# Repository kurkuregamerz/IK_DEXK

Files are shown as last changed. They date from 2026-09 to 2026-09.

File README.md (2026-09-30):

# IK DEXK 
IK DEXK is a macropad that has 16 MX Keyboard switches and 1 OLED 0.91 inch Display.

## Preview of Designs  
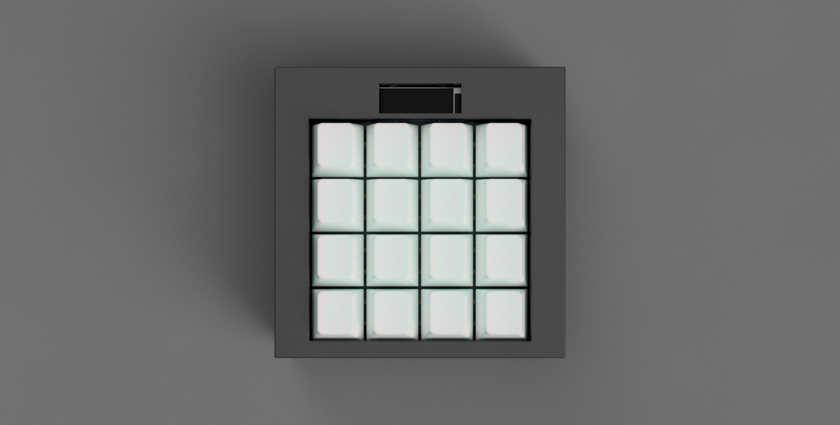
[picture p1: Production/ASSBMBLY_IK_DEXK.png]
  
  
  
  
  
  
## Features
*  It includes an 0.91 inch OLED display.
*  Custom Macros for efficiency.
*  Has high performance Cherry MX Switches with white keycaps.
*  Custom PCB and Case.

## THE PROCESS 
I at first designed the Macropad to be 3x3 but during designing I made some mistakes which later in firmware development caused a huge problem.
So when I ran into that problem I thought that now I know how things work so why not make it larger. That is why I made the macropad 4x4.
Here are some images of design which were used at first.
  
  

# BILL OF MATARIALS
* TOTAL IS $54.86 with delivery charge.<br/>
<table>
  <tr>
    <th>ITEM</th>
    <th>SOURCE</th>
    <th>PRICE</th>
    <th>DELIVERY CHARGE</th>
    <th>TOTAL</th>
  </tr>
  <tr>
    <td>PCB</td>
    <td>JLCPCB</td>
    <td>$ 4.00</td>
    <td>$ -</td>
    <td>$ 4.00</td>
  </tr>
  <tr>
    <td>CASE-BOTTOM</td>
    <td>JLC3DP</td>
    <td>$ 22.34</td>
    <td>$ 24.58</td>
    <td>$ 46.92</td>
  </tr>
   <tr>
    <td>CASE-TOP</td>
    <td>JLC3DP</td>
    <td>$ 3.94</td>
    <td>$ -</td>
    <td>$ 3.94</td>
  </tr>
  <tr>
    <td>HACKPAD KIT</td>
    <td>HACKCLUB</td>
    <td>$ -</td>
    <td>$ -</td>
    <td>$ 0.00</td>
  </tr>
  <tr>
    <td>TOTAL</td>
    <td></td>
    <td>$ 30.28</td>
    <td>$ 24.58</td>
    <td>$ 54.86</td>
  </tr>
</table>

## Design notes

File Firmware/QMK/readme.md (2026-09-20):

# ik_dexk

ik_dexk

*A short description of the keyboard/project*

* Keyboard Maintainer: [Ishan Karar](https://github.com/kurkuregamerz)
* Hardware Supported: *The PCBs, controllers supported*
* Hardware Availability: *Links to where you can find this hardware*

Make example for this keyboard (after setting up your build environment):

    make ik_dexk:default

Flashing example for this keyboard:

    make ik_dexk:default:flash

See the [build environment setup](https://docs.qmk.fm/#/getting_started_build_tools) and the [make instructions](https://docs.qmk.fm/#/getting_started_make_guide) for more information. Brand new to QMK? Start with our [Complete Newbs Guide](https://docs.qmk.fm/#/newbs).

## Bootloader

Enter the bootloader in 3 ways:

* **Bootmagic reset**: Hold down the key at (0,0) in the matrix (usually the top left key or Escape) and plug in the keyboard
* **Physical reset button**: Briefly press the button on the back of the PCB - some may have pads you must short instead
* **Keycode in layout**: Press the key mapped to `QK_BOOT` if it is available

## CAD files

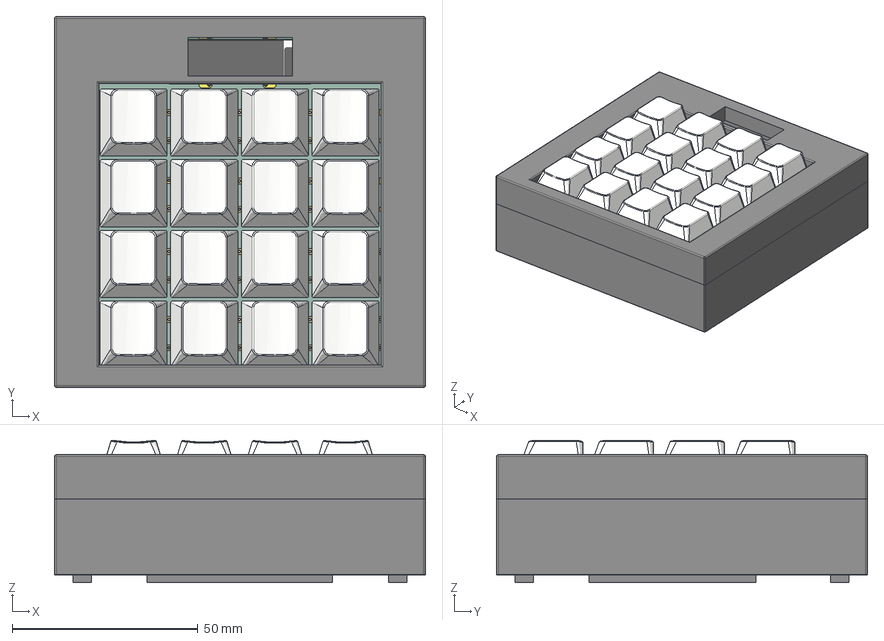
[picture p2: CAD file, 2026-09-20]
CAD/ASSBMBLY_IK_DEXK.step
100.0 x 100.0 x 38.3 mm

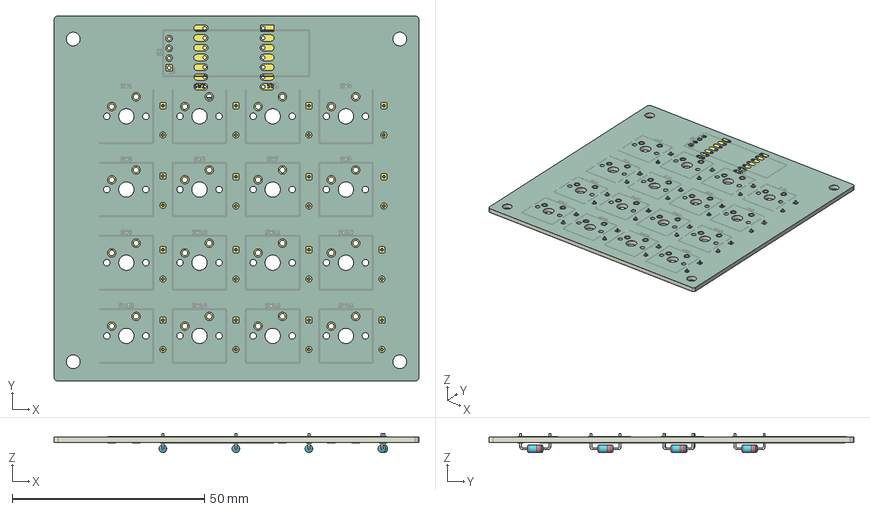
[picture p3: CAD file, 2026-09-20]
pcb/IK_DEXK_PCB.step
95.0 x 95.0 x 5.01 mm
D_DO-35_SOD27_P7.62mm_Horizontal x 16
IK_DEXK_copper
IK_DEXK_silkscreen x 2
IK_DEXK_soldermask x 2
IK_DEXK_PCB

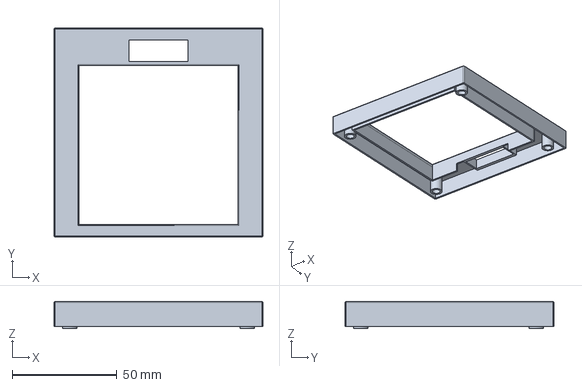
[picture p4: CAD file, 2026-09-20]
Production/CASE TOP.step
100.0 x 100.0 x 13.0 mm

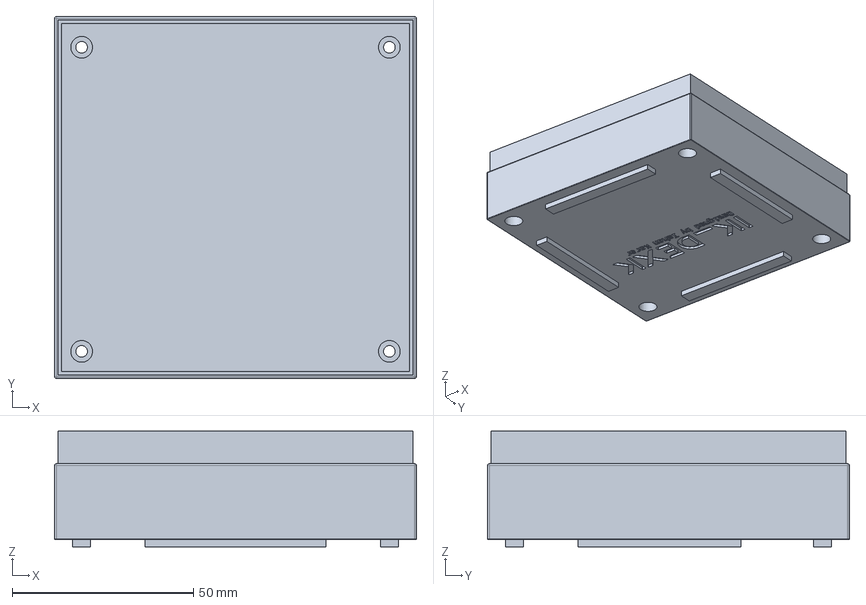
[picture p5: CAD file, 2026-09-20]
Production/CASE BOTTOM.step
100.0 x 100.0 x 32.0 mm

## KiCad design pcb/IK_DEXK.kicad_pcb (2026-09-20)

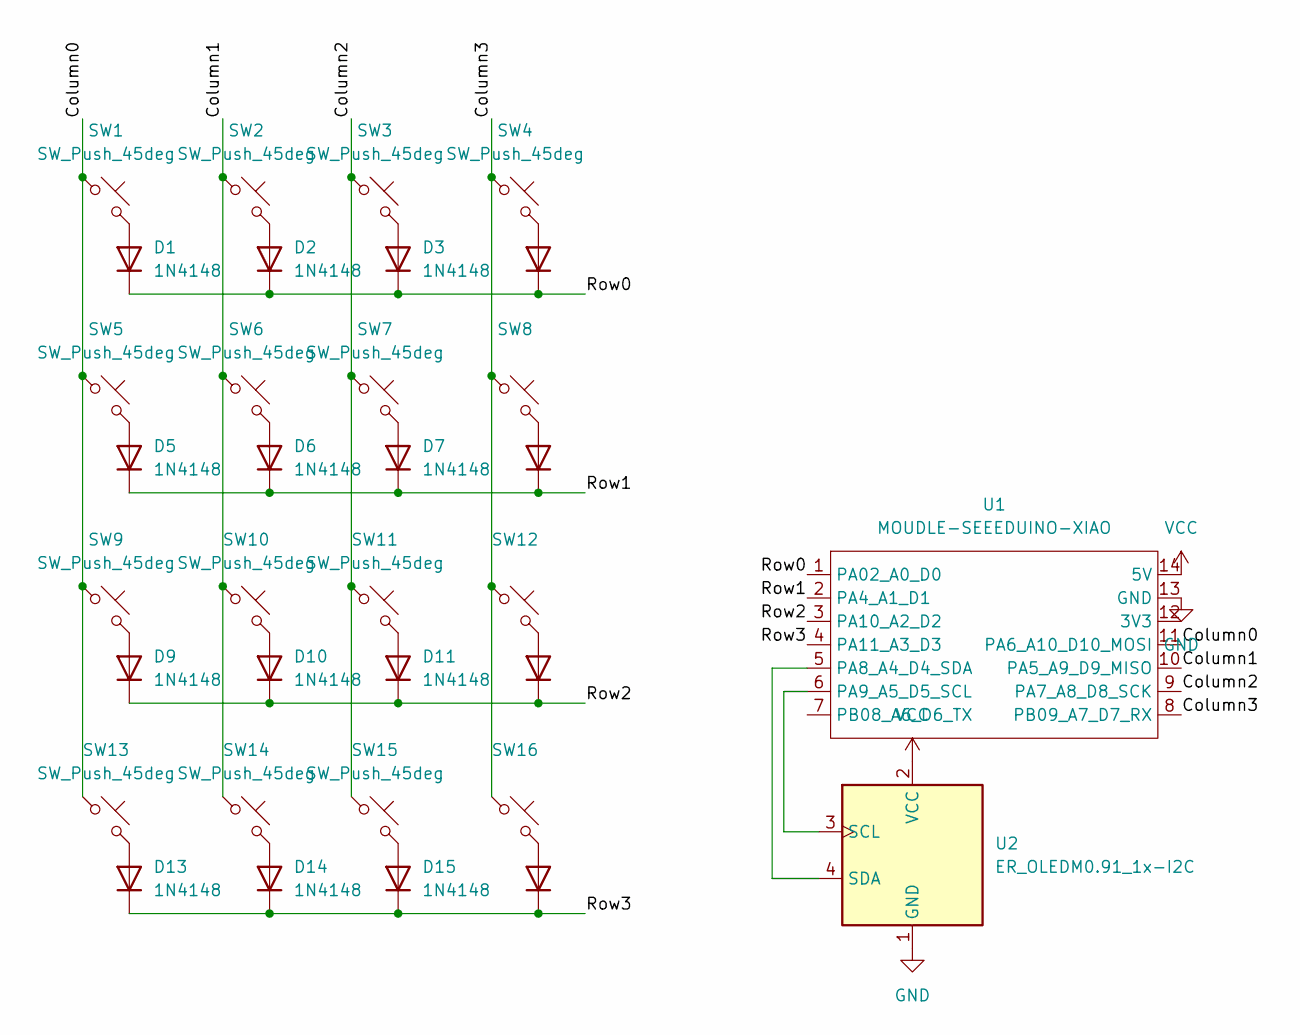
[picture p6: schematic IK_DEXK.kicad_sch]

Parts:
D1, D2, D3, D4, D5, D6, D7, D8, D9, D10, D11, D12, D13, D14, D15, D16: 1N4148; D_DO-35_SOD27_P7.62mm_Horizontal
SW1, SW2, SW3, SW4, SW5, SW6, SW7, SW8, SW9, SW10, SW11, SW12, SW13, SW14, SW15, SW16: SW_Push_45deg; SW_Cherry_MX_1.00u_PCB
U1: MOUDLE-SEEEDUINO-XIAO; XIAO-Generic-Hybrid-14P-2.54-21X17.8MM
U2: ER_OLEDM0.91_1x-I2C

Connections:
/Column0: SW1.1, SW5.1, SW9.1, SW13.1, U1.11 (PA6_A10_D10_MOSI)
/Column1: SW2.1, SW6.1, SW10.1, SW14.1, U1.10 (PA5_A9_D9_MISO)
/Column2: SW3.1, SW7.1, SW11.1, SW15.1, U1.9 (PA7_A8_D8_SCK)
/Column3: SW4.1, SW8.1, SW12.1, SW16.1, U1.8 (PB09_A7_D7_RX)
/Row0: D1.1 (K), D2.1 (K), D3.1 (K), D4.1 (K), U1.1 (PA02_A0_D0)
/Row1: D5.1 (K), D6.1 (K), D7.1 (K), D8.1 (K), U1.2 (PA4_A1_D1)
/Row2: D9.1 (K), D10.1 (K), D11.1 (K), D12.1 (K), U1.3 (PA10_A2_D2)
/Row3: D13.1 (K), D14.1 (K), D15.1 (K), D16.1 (K), U1.4 (PA11_A3_D3)
GND: U1.13 (GND), U2.1 (GND)
unnamed: D1.2 (A), SW1.2
unnamed: D2.2 (A), SW2.2
unnamed: D3.2 (A), SW3.2
unnamed: D4.2 (A), SW4.2
unnamed: D5.2 (A), SW5.2
unnamed: D6.2 (A), SW6.2
unnamed: D7.2 (A), SW7.2
unnamed: D8.2 (A), SW8.2
unnamed: D9.2 (A), SW9.2
unnamed: D10.2 (A), SW10.2
unnamed: D11.2 (A), SW11.2
unnamed: D12.2 (A), SW12.2
unnamed: D13.2 (A), SW13.2
unnamed: D14.2 (A), SW14.2
unnamed: D15.2 (A), SW15.2
unnamed: D16.2 (A), SW16.2
unnamed: U1.5 (PA8_A4_D4_SDA), U2.4 (SDA)
unnamed: U1.6 (PA9_A5_D5_SCL), U2.3 (SCL)
VCC: U1.14 (5V), U2.2 (VCC)

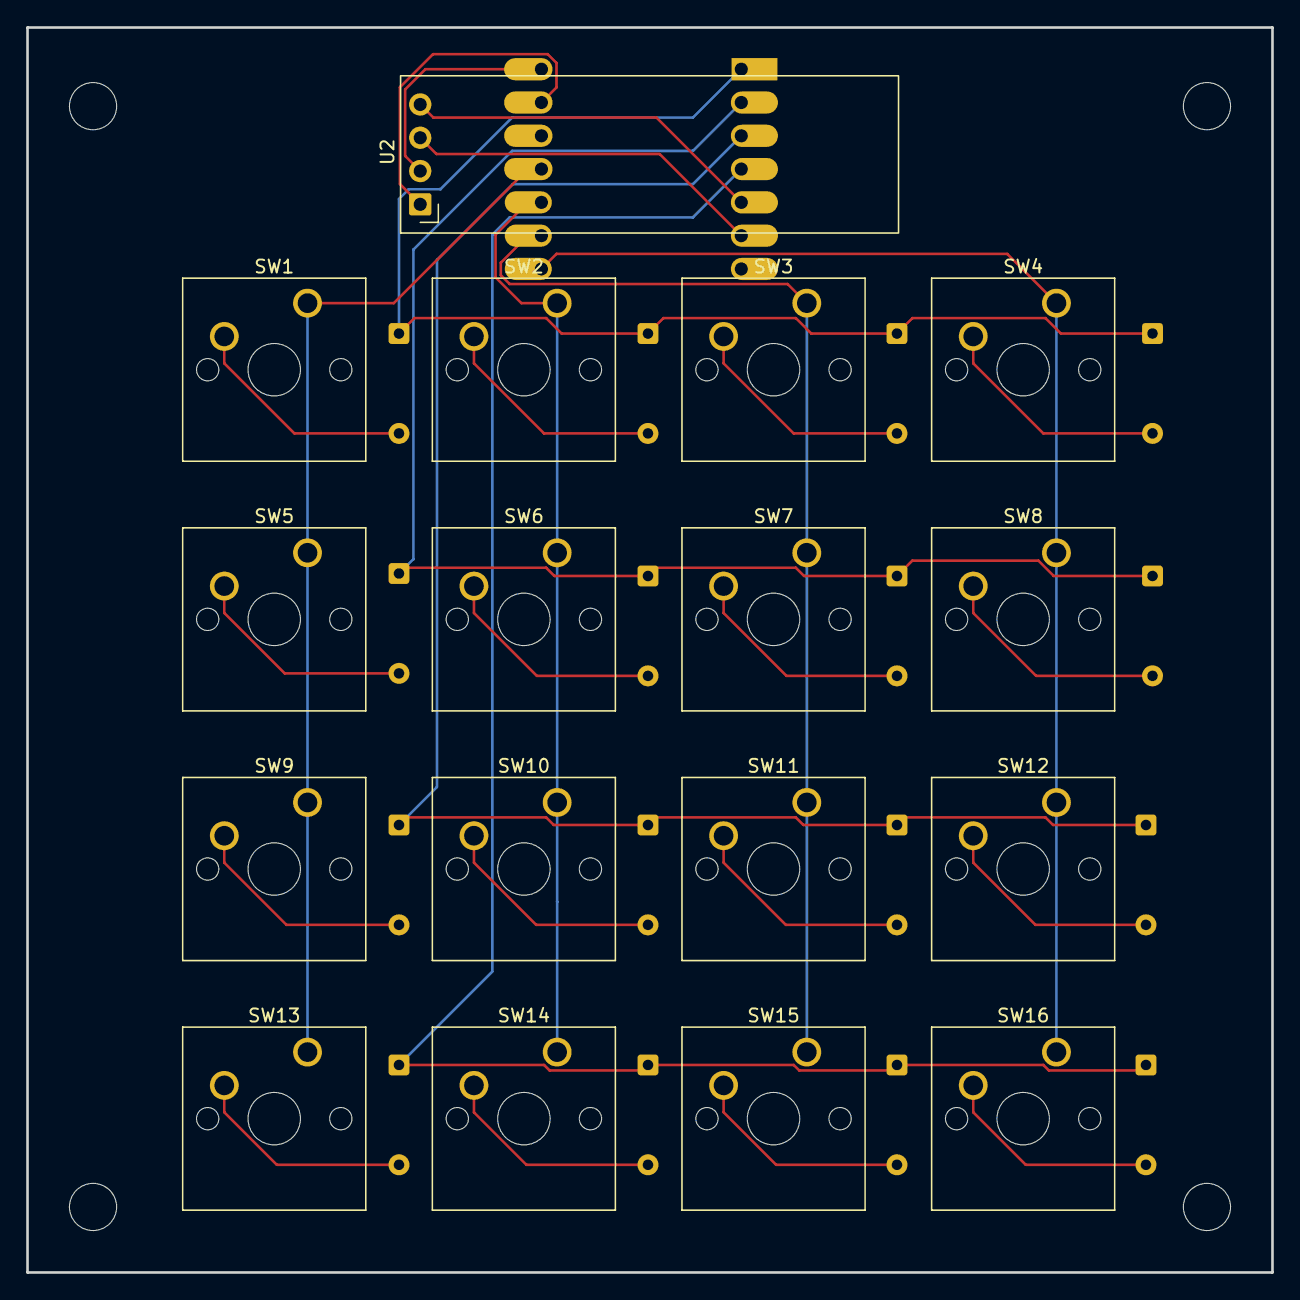
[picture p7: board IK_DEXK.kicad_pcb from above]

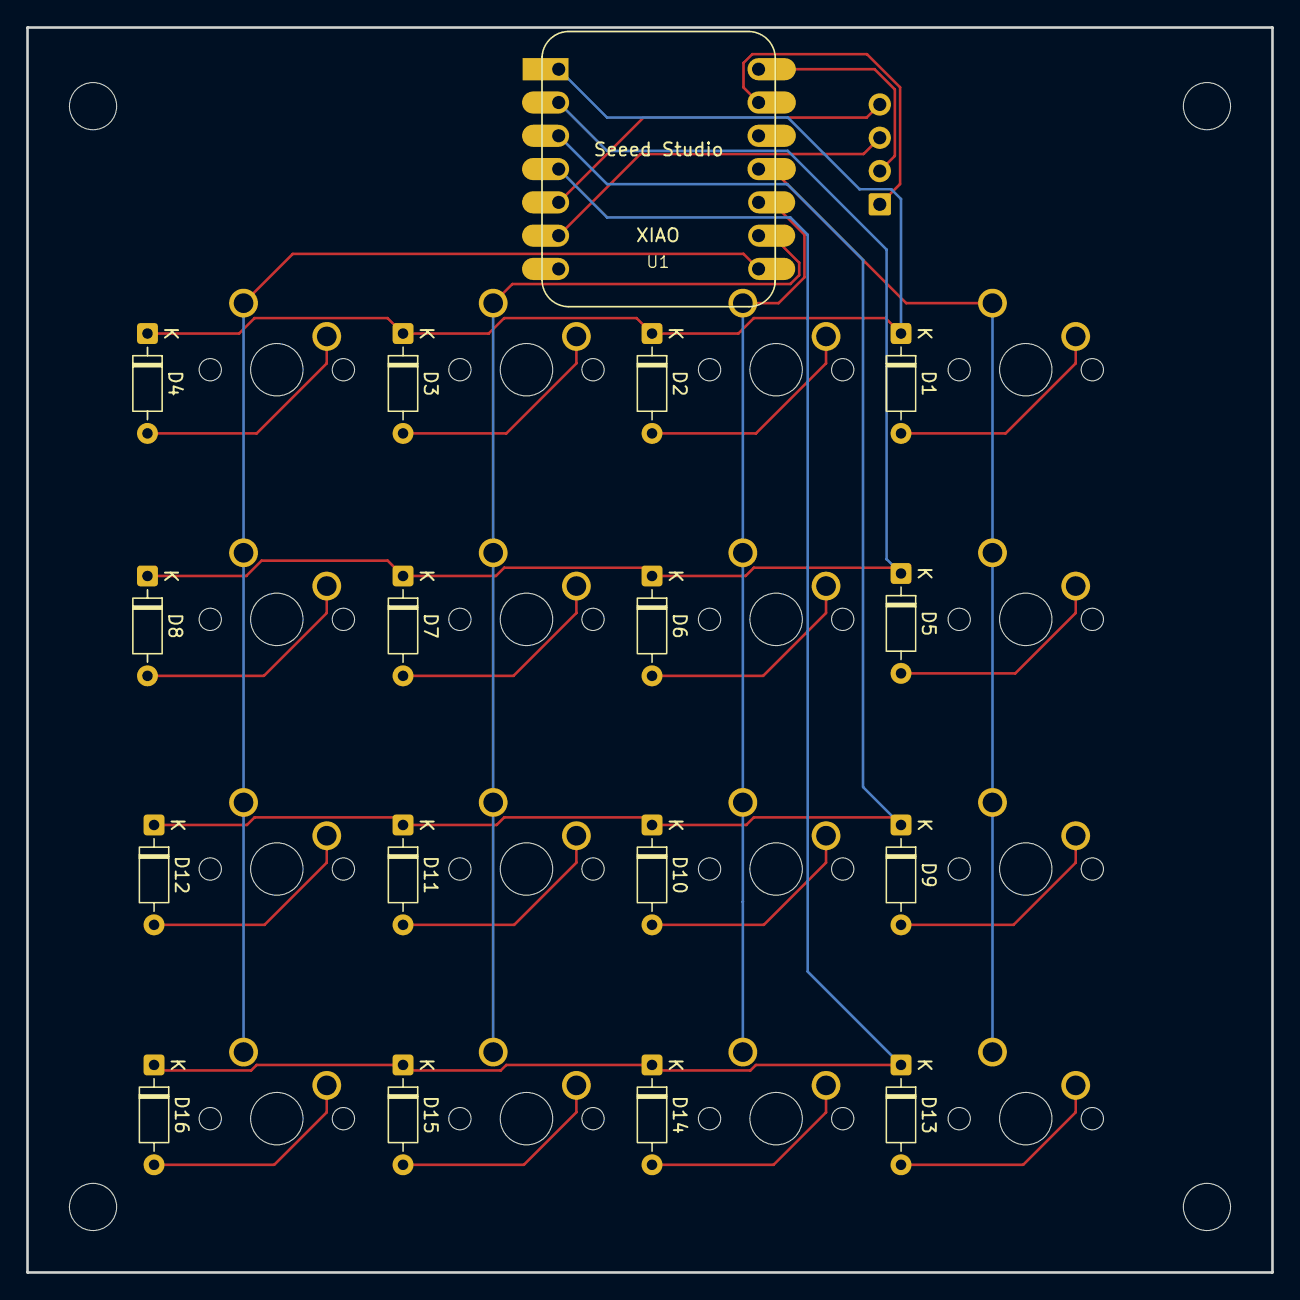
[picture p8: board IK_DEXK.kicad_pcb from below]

Board: 2 copper layers, 95.0 x 95.0 mm, 34 parts (17 on the bottom side), 28 nets.

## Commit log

2026-09-11 Commit 1 Added PCB folder
    [IK_DEXK-B_Cu.gbr, IK_DEXK-B_Mask.gbr, IK_DEXK-B_Paste.gbr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]
2026-09-16 added pcb
    [IK_DEXK-B_Cu.gbr, IK_DEXK-B_Mask.gbr, IK_DEXK-B_Paste.gbr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]
2026-09-26 bom added
2026-10-29 BOM.csv ADDED
2026-10-30 BOM.csv changed
2026-10-30 Hyperlink of BOM.csv added to README.md
